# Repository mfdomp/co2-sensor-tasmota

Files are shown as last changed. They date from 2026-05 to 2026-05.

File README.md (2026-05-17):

# CO2 Sensor — ESP32 + Tasmota

Monitor de qualidade do ar com ESP32, sensor SCD41, display OLED, RTC e log em cartão SD. O firmware é o Tasmota 15.3.0.4 com script Berry (`autoexec.be`) que controla o display SSD1306 diretamente via I2C, sincroniza o DS3231 via NTP no boot e grava logs CSV no cartão SD.

## Funcionalidades

- Leitura de CO2 (ppm), temperatura (°C) e umidade relativa (%) via SCD41
- Display OLED SSD1306 128×64 com driver próprio em Berry (fonte 5×7, sem subsistema Display do Tasmota)
- Relógio em tempo real DS3231 — lido diretamente via I2C, sincronizado por NTP a cada boot
- Log CSV no cartão SD com timestamp local, gravado a cada 10 s; nome de arquivo gerado pela data/hora do boot
- Watchdog de software: reinicia o ESP32 se o loop principal travar por mais de 60 s
- Calibração forçada do SCD41 via função Berry `calibrar_scd41(ppm)` acessível pelo console
- Sem código C/C++ customizado — só Berry script + configuração Tasmota

## Implementações futuras

- Telemetria MQTT (publicação de leituras via broker MQTT usando o subsistema nativo do Tasmota)

## Hardware

| Componente | Descrição |
|---|---|
| ESP32-D0WD-V3 | Módulo principal (ex.: DevKit-C V4 38 pinos) |
| SCD41 | Sensor CO2 fotoacústico ± 40 ppm (I2C 0x62) |
| SSD1306 | Display OLED 0,96″ 128×64 px (I2C 0x3C) |
| DS3231 | Módulo RTC alta precisão (I2C 0x68) |
| Módulo MicroSD | Adaptador SPI para cartão MicroSD |

Todos os dispositivos I2C compartilham o mesmo barramento (GPIO 21/22).  
O cartão SD usa SPI dedicado (GPIO 5/18/19/23).

## Estrutura do repositório

```
co2-sensor-tasmota/
├── README.md
├── LICENSE
├── docs/
│   ├── bom.md          # Bill of Materials detalhada
│   ├── wiring.md       # Diagrama de conexões e pinagem
│   └── setup.md        # Guia completo de configuração
├── firmware/
│   ├── autoexec.be     # Script Berry principal (carregar no Tasmota)
│   └── tasmota/
│       ├── tasmota_template.json  # Template de GPIOs para Tasmota
│       └── backlog_config.txt     # Comandos de configuração via console
└── hardware/
    └── pinout.md       # Tabela de pinos ESP32 ↔ periféricos
```

## Acesso à Interface Web

### Android (recomendado para uso em campo)
1. Conecte ao WiFi `Sensor-XXXXXX`
2. Quando aparecer "Esta rede não tem internet, deseja continuar?" — confirme **Sim**
3. Abra o navegador e acesse `http://192.168.4.1`

### Windows
1. Conecte ao WiFi `Sensor-XXXXXX`
2. Ignore o aviso "Ação necessária"
3. Abra o navegador **manualmente** e acesse `http://192.168.4.1`
4. **Atenção:** O Windows pode desconectar automaticamente redes sem internet. Se isso ocorrer, reconecte e acesse rapidamente.
   - Para evitar: Configurações → Rede e Internet → WiFi → `Sensor-XXXXXX` → Propriedades → desabilitar troca automática de rede

### iOS
1. Conecte ao WiFi `Sensor-XXXXXX`
2. Ignore o aviso de portal cativo
3. Abra o Safari e acesse `http://192.168.4.1`

### Endereço fixo
O sensor sempre opera em `http://192.168.4.1` no modo AP.

## Início rápido

1. **Grave o firmware Tasmota** no ESP32 — veja [`docs/setup.md`](docs/setup.md).
2. **Conecte os componentes** conforme [`hardware/pinout.md`](hardware/pinout.md).
3. **Configure os GPIOs e drivers** via console Tasmota com os comandos em [`firmware/tasmota/backlog_config.txt`](firmware/tasmota/backlog_config.txt).
4. **Carregue o script Berry** copiando [`firmware/autoexec.be`](firmware/autoexec.be) via Tasmota File Manager (`Tools → Manage File System`).
5. **Reinicie** o dispositivo. O display acende ~21 s após o boot.

## Layout do display

```
28/04/2025        ← data (DS3231)
14:30             ← hora (DS3231)

CO2:512 ppm       ← leitura SCD41

T:22.5C H:45%     ← temperatura e umidade

192.168.1.42      ← IP Wi-Fi
```

Linha em branco entre grupos = página vazia no SSD1306 (fonte 5×7, 6 px por coluna).

## Log CSV

O arquivo é criado no cartão SD com nome baseado na data e hora do boot:

```
/sd/co2_20250428_1430.csv
```

Cabeçalho e formato:

```csv
datetime,co2,temperature,humidity
28/04/2025 14:30:00,512,22.5,45
28/04/2025 14:30:10,515,22.5,45
```

Gravação a cada **10 segundos**. Cada reinicialização cria um novo arquivo.

## Calibração do SCD41

Para calibração forçada pelo ar exterior (~420 ppm), execute no console Tasmota:

```
Br calibrar_scd41(420)
```

A função interrompe a medição, aguarda 3 s, aplica a calibração forçada (Forced Recalibration — FRC) e retoma automaticamente.

## Dependências de firmware

- [Tasmota 15.3.0.4](https://github.com/arendst/Tasmota) — build `tasmota32.bin`
- Nenhuma biblioteca externa — tudo incluso no Tasmota

## Licença

MIT — veja [`LICENSE`](LICENSE).

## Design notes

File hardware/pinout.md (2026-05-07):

# Pinagem — ESP32 DevKit-C V4 × Periféricos

## Barramento I2C (GPIO 21 / 22)

Todos os três dispositivos compartilham o **mesmo barramento I2C**. Os resistores de pull-up (4,7 kΩ para 3,3 V) devem estar presentes — muitos módulos breakout já os incluem.

| Sinal I2C | GPIO ESP32 | SCD41 | SSD1306 | DS3231 |
|---|---|---|---|---|
| SDA | **GPIO 21** | SDA | SDA | SDA |
| SCL | **GPIO 22** | SCL | SCL | SCL |
| VCC | 3,3 V | VDD | VCC | VCC |
| GND | GND | GND | GND | GND |

Endereços I2C padrão:

| Dispositivo | Endereço (hex) | Endereço (decimal) |
|---|---|---|
| SCD41 | 0x62 | 98 |
| SSD1306 | 0x3C | 60 |
| DS3231 | 0x68 | 104 |

> Para confirmar os endereços no Tasmota: `I2CScan` no console.

## SPI — Módulo MicroSD (GPIO 5/18/19/23)

| Sinal SPI | GPIO ESP32 | Módulo SD |
|---|---|---|
| MOSI | **GPIO 23** | MOSI / DI |
| MISO | **GPIO 19** | MISO / DO |
| CLK | **GPIO 18** | SCK / CLK |
| CS | **GPIO 5** | CS / SS |
| VCC | 3,3 V | VCC |
| GND | GND | GND |

> Use módulos SD com nível lógico 3,3 V ou que incluam divisor de tensão. O ESP32 **não tolera** 5 V nos pinos de I/O.

## Diagrama de conexão simplificado

```
ESP32 DevKit-C V4
┌─────────────────────────────────────────────┐
│                                             │
│  3V3 ──┬─── VCC (SCD41)                    │
│        ├─── VCC (SSD1306)                  │
│        ├─── VCC (DS3231)                   │
│        └─── VCC (SD Module)                │
│                                             │
│  GND ──┬─── GND (SCD41)                   │
│        ├─── GND (SSD1306)                  │
│        ├─── GND (DS3231)                   │
│        └─── GND (SD Module)                │
│                                             │
│  GPIO21 (SDA) ──┬─── SDA (SCD41)          │
│                 ├─── SDA (SSD1306)         │
│                 └─── SDA (DS3231)          │
│                                             │
│  GPIO22 (SCL) ──┬─── SCL (SCD41)          │
│                 ├─── SCL (SSD1306)         │
│                 └─── SCL (DS3231)          │
│                                             │
│  GPIO23 (MOSI) ─── DI  (SD Module)        │
│  GPIO19 (MISO) ─── DO  (SD Module)        │
│  GPIO18 (CLK)  ─── SCK (SD Module)        │
│  GPIO5  (CS)   ─── CS  (SD Module)        │
│                                             │
└─────────────────────────────────────────────┘
```

## Recomendações de montagem

- Mantenha os fios I2C com **menos de 20 cm** para evitar problemas de integridade de sinal.
- O SCD41 precisa de **circulação de ar** — não enclausure hermeticamente.
- Coloque o DS3231 **longe de fontes de calor** para manter a precisão do RTC.
- Um capacitor de 100 nF entre VCC e GND próximo a cada módulo reduz ruído na alimentação.

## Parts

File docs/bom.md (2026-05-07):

# Bill of Materials (BOM)

Revisão: 1.0 — 2025

## Componentes principais

| # | Componente | Fabricante | Part Number | Qtd | Notas |
|---|---|---|---|---|---|
| 1 | Módulo ESP32-DevKit-C V4 | Espressif / genérico | ESP32-D0WD-V3 | 1 | 38 pinos, USB-C preferível |
| 2 | Sensor CO2 SCD41 | Sensirion | SCD41 (breakout) | 1 | I2C 0x62; alimentação 3,3 V |
| 3 | Display OLED 0,96″ 128×64 | SSD1306 | genérico | 1 | I2C 0x3C; tensão 3,3 V ou 5 V |
| 4 | Módulo RTC DS3231 | Maxim / genérico | DS3231 (breakout) | 1 | I2C 0x68; inclui bateria CR2032 |
| 5 | Módulo MicroSD SPI | genérico | — | 1 | Nível lógico 3,3 V |

## Componentes passivos e auxiliares

| # | Componente | Valor | Qtd | Notas |
|---|---|---|---|---|
| 6 | Resistor pull-up I2C | 4,7 kΩ 1/4 W | 2 | SDA e SCL; omitir se os módulos já têm pull-up integrado |
| 7 | Capacitor de desacoplamento | 100 nF cerâmico | 4 | Um por módulo, próximo ao VCC |
| 8 | Capacitor bulk | 10 µF eletrolítico | 1 | Na alimentação 3,3 V |
| 9 | Bateria CR2032 | — | 1 | Para o DS3231 |

## Alimentação

| # | Item | Especificação | Qtd | Notas |
|---|---|---|---|---|
| 10 | Fonte USB 5 V | ≥ 1 A | 1 | O ESP32 consome ~240 mA em pico de TX Wi-Fi |
| 11 | Cabo USB (gravação/energia) | USB-A → USB-C ou Micro-USB | 1 | Conforme o conector do módulo |
| 12 | Regulador 3,3 V (opcional) | AMS1117-3.3 | 1 | Somente se a placa DevKit não tiver regulador interno |

## Fixação e enclosure

| # | Item | Qtd | Notas |
|---|---|---|---|
| 13 | Protoboard / PCB perfurada | 1 | Para prototipagem |
| 14 | Jumpers Macho-Macho 20 cm | 20 | Para prototipagem |
| 15 | Caixa plástica ≥ 80×60×30 mm | 1 | Furar para saídas de ar no SCD41 |
| 16 | Parafuso M3 × 6 mm | 4 | Fixação da placa na caixa |

## Consumo estimado

| Componente | Corrente típica (3,3 V) |
|---|---|
| ESP32 (Wi-Fi ativo) | 160–240 mA |
| SCD41 | 15 mA (medição) / 0,4 mA (espera) |
| SSD1306 | 10–20 mA |
| DS3231 | < 1 mA |
| Módulo SD (leitura/escrita) | 50–100 mA |
| **Total estimado** | **~250–380 mA @ 3,3 V** |

## Custo estimado (2025, mercado brasileiro)

| Componente | Preço aproximado (R$) |
|---|---|
| ESP32-DevKit-C V4 | R$ 30–50 |
| SCD41 (breakout) | R$ 200–280 |
| SSD1306 OLED 0,96″ | R$ 15–25 |
| DS3231 (módulo com bateria) | R$ 15–25 |
| Módulo MicroSD | R$ 8–15 |
| Componentes passivos | R$ 5–10 |
| MicroSD card 8–32 GB | R$ 15–30 |
| **Total estimado** | **R$ 288–435** |

> O SCD41 é o componente mais caro (~60–65% do custo total). Uma alternativa econômica é o MH-Z19C (~R$ 80), porém com menor precisão e sem medição de umidade.

## Onde comprar

- [Filipeflop](https://www.filipeflop.com)
- [Makerstore](https://www.makerstore.com.br)
- [AliExpress](https://www.aliexpress.com) — SCD41 breakout da Sensirion
- [Mouser Brasil](https://br.mouser.com) — SCD41 original Sensirion

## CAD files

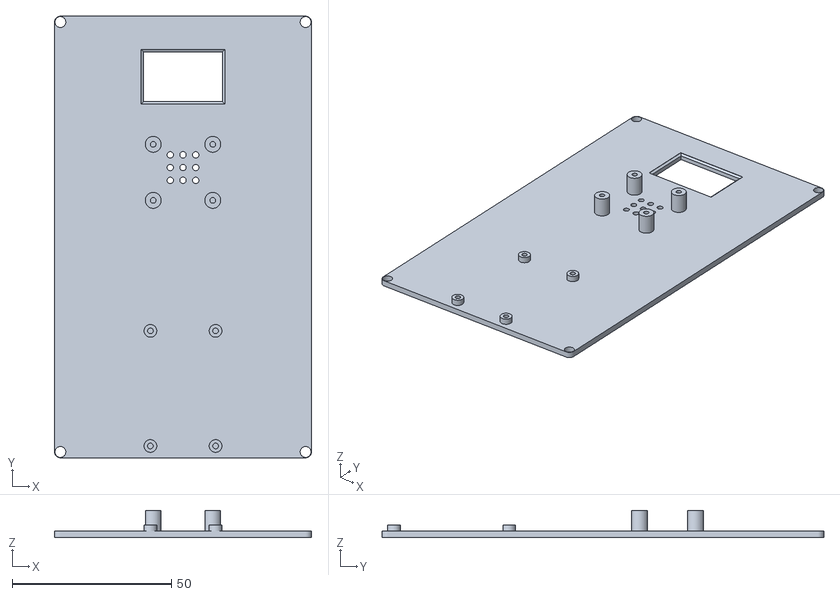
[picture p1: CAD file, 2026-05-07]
enclosure/stl/enclosure_lid.stl
80.7 x 138.7 x 8.50

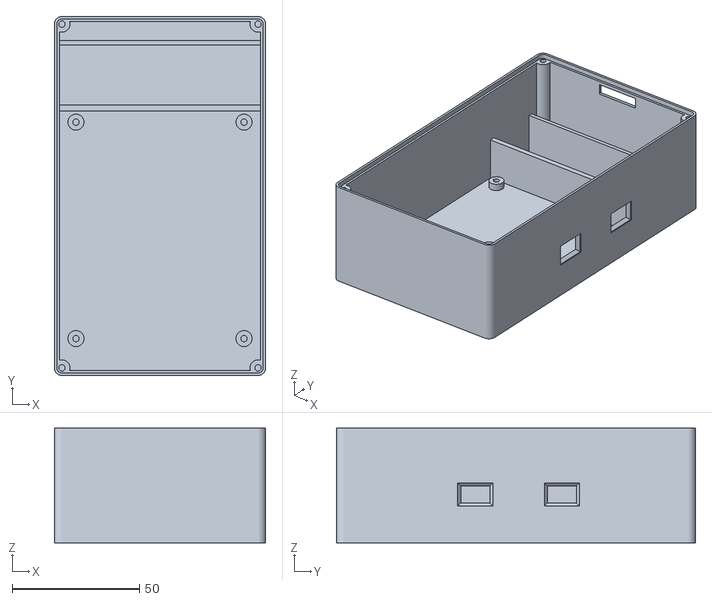
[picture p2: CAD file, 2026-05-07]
enclosure/stl/enclosure_base.stl
83.0 x 141.0 x 45.0

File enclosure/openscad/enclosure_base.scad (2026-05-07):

use <enclosure_v5_3_1.scad>
base();

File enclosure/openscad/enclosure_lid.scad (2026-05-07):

use <enclosure_v5_3_1.scad>
rotate([180, 0, 0]) translate([0, -125, -10]) lid();

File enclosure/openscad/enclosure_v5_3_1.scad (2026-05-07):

/* ============================================================
   ENCLOSURE v5
   83 × 141 × 47mm total  (base 45mm + tampa plana 2mm)
   Parede 2mm  |  Cantos R3mm

   MUDANÇAS v5 (em relação à v4):
   - BASE_H  30 → 45mm (+15mm)
   - Tampa   sem paredes laterais — placa plana 2mm
   - Encaixe rebaixo (rabbet) 1mm × 2mm no topo da base
     substitui o lábio/press-fit anterior
   - USB_Z   fixo no valor original (Z=11.6mm, base=30mm)
             NÃO recentralizado na nova altura
   - Slot MicroSD migra da tampa para a parede traseira da base
   - LIP_GAP=0.15mm (folga placa/rebaixo)

   COMPARTIMENTOS BASE:
     PCB  : Y  12..104 = 102mm de profundidade
     Rib  : Y 104..106 (furo Ø6mm fio da bateria)
     BAT  : Y 109..130 (bateria 18650: 75.6×21×18.2mm)
   ============================================================ */

$fn   = 64;
EPS   = 0.01;

// ── Caixa ────────────────────────────────────────────────────
ENC_W  = 83;
ENC_L  = 141;
WALL   = 2;
C_RAD  = 3;
BASE_H = 45;   // era 30mm — +15mm

// ── Tampa plana ───────────────────────────────────────────────
// Sem paredes laterais; standoffs pendurados para baixo.
// IT = distância do fundo da placa até referência dos componentes
// (inalterado → mantém posições OLED/SCD/MSD)
IT   = 13;

// ── Encaixe rebaixo (rabbet) ──────────────────────────────────
// Topo das paredes da base recebe um degrau de 1mm × 2mm.
// A placa tampa (80.7 × 138.7mm) assenta nesse degrau.
RABB_T  = 1.0;        // profundidade inward do rebaixo (1mm)
RABB_D  = WALL;       // altura do rebaixo = espessura da placa (2mm)
LIP_GAP = 0.15;       // folga lateral placa/degrau

LID_OFFSET = RABB_T + LIP_GAP;            // = 1.15mm
LID_W      = ENC_W - 2*LID_OFFSET;        // = 80.70mm
LID_L      = ENC_L - 2*LID_OFFSET;        // = 138.70mm
LID_R      = max(0.5, C_RAD - LID_OFFSET);// = 1.85mm

// ── Parafusos M3 ─────────────────────────────────────────────
BOSS_D   = 6;
BOSS_M   = 3;     // boss integrado ao canto (centro em 3,3)
PILOT_D  = 2.5;   // furo piloto auto-roscante no boss
SCREW_CL = 3.4;   // clearance M3

// ── PCB principal ─────────────────────────────────────────────
PCB_W   = 70;
PCB_L   = 90;
HOLE_DW = 66;
HOLE_DL = 85;
POST_OD = 6;
STAND_H = 3;
PCB_X0  = WALL + (ENC_W - 2*WALL - PCB_W) / 2;  // = 6.5mm
PCB_Y0  = WALL + 10;                              // = 12mm

// ── Parede divisória + furo fio bateria ──────────────────────
WIRE_RIB_Y = PCB_Y0 + PCB_L + 2;  // = 104mm
WIRE_RIB_T = 2.0;
WIRE_D     = 6.0;
WIRE_X     = ENC_W / 2;
WIRE_Z     = WALL + 18.2 / 2;     // centro vertical da bateria

// ── Bateria 18650 ─────────────────────────────────────────────
BAT_L    = 75.6;
BAT_W    = 21.0;
BAT_H    = 18.2;
BAT_RAIL = 1.5;
BAT_X0   = WALL + (ENC_W - 2*WALL - BAT_L) / 2;
BAT_Y0   = WIRE_RIB_Y + WIRE_RIB_T + 3;  // = 109mm

// ── Mini USB (Z FIXO — posição original com BASE_H=30mm) ─────
USB_W      = 7.39;
USB_H      = 2.73;
USB_MARGIN = 2.0;
USB_HW     = USB_W + 2*USB_MARGIN;
USB_HH     = USB_H + 2*USB_MARGIN;
USB_CH     = 1.2;
USB1_Y     = PCB_Y0 + (38.2 + (PCB_L - 43.2)) / 2; // = 54.5mm
USB2_Y     = PCB_Y0 + (74.0 + (PCB_L - 11.0)) / 2; // = 88.5mm
USB_Z      = (30 - USB_HH) / 2 + 4 +3.5 + 1.5;  // +4mm solicitado → ~15.6mm

// ── OLED (posições do v3_1) ───────────────────────────────────
OLED_PCB_W   = 27.2;
OLED_PCB_L   = 28.3;
OLED_HOLE_DW = 23.89;
OLED_HOLE_DL = 25;
OLED_WIN_W   = 24.7;
OLED_WIN_L   = 15.55;
OLED_STAND   = 1.5;
OLED_POST_D  = 5.0;
OLED_SCREW   = 1.8;
OLED_CX      = ENC_W / 2;
OLED_CY      = WALL + 4 + OLED_PCB_L / 2;

// ── SCD41 (posições do v3_1) ──────────────────────────────────
SCD_PCB_W    = 23.0;
SCD_PCB_L    = 21.8;
SCD_HOLE_DW  = 18.7;
SCD_HOLE_DL  = 17.6;
SCD_SENS_W   = 8.0;
SCD_SENS_L   = 8.0;
SCD_SENS_OFF = 5.4;
SCD_STAND    = 6.5;
SCD_POST_D   = 5.0;
SCD_SCREW    = 1.8;
SCD_CX       = ENC_W / 2;
SCD_Y0       = WALL + 4 + OLED_PCB_L + 5;
SCD_CY       = SCD_Y0 + SCD_PCB_L / 2;
SCD_SENS_CX  = SCD_CX;
SCD_SENS_CY  = SCD_Y0 + SCD_SENS_OFF + SCD_SENS_L / 2;

// ── MicroSD ───────────────────────────────────────────────────
MSD_PCB_W    = 24.2;
MSD_PCB_L    = 41.9;
MSD_HOLE_DW  = 20.45;
MSD_HOLE_DL  = 36.15;
MSD_PCB_H    = 1.59;
MSD_TOT_H    = 3.56;
MSD_CARD_W   = 18.0;
MSD_CARD_H   = 3.6;
MSD_STAND    = 2.0;
MSD_POST_D   = 4.0;
MSD_SCREW    = 1.8;
MSD_CX       = ENC_W / 2;
MSD_Y1       = ENC_L - WALL;
MSD_Y0       = MSD_Y1 - MSD_PCB_L;
MSD_CY       = MSD_Y0 + MSD_PCB_L / 2;

// Posição Z do slot do cartão — referenciada à BASE (Z absoluto)
// Placa tampa fundo: Z = BASE_H - WALL = 43mm
// PCB MSD topo:      Z = 43 - MSD_STAND = 41mm
// PCB MSD fundo:     Z = 41 - MSD_PCB_H = 39.41mm
// Cartão fundo:      Z = 39.41 - (MSD_TOT_H - MSD_PCB_H) = 37.44mm
MSD_PCB_TOP_BASE  = BASE_H - WALL - MSD_STAND;
MSD_PCB_BOT_BASE  = MSD_PCB_TOP_BASE - MSD_PCB_H;
MSD_CARD_BOT_BASE = MSD_PCB_BOT_BASE - (MSD_TOT_H - MSD_PCB_H);
MSD_CARD_CZ_BASE  = (MSD_PCB_BOT_BASE + MSD_CARD_BOT_BASE) / 2;
MSD_SLOT_M        = 0.5;   // margem extra no slot do cartão

// ════════════════════════════════════════════════════════════
// UTILITÁRIO
// ════════════════════════════════════════════════════════════
module rbox(w, l, h, r) {
    R = (r == undef) ? C_RAD : r;
    linear_extrude(h)
        hull()
            for (xi = [R, w-R], yi = [R, l-R])
                translate([xi, yi]) circle(r = R);
}

// ════════════════════════════════════════════════════════════
// BASE (45mm)
//
// Topo das paredes tem rebaixo de 1mm×2mm para receber a tampa.
// Boss de canto vai até BASE_H; exempt do rebaixo para manter
// acesso ao parafuso M3.
// USB fixo em Z=11.6mm (posição original).
// Slot MicroSD na parede traseira (Y=ENC_L).
// ════════════════════════════════════════════════════════════
module base() {

    pcb_cx = PCB_X0 + PCB_W/2;
    pcb_cy = PCB_Y0 + PCB_L/2;
    EE = 0.5;   // embute sólidos EE mm no fundo
    EX = 0.15;  // margem de exemption

    difference() {

        // ═══════════════════════════════════════
        // SÓLIDOS
        // ═══════════════════════════════════════
        union() {
            // Casco externo (45mm)
            rbox(ENC_W, ENC_L, BASE_H);

            // Boss de canto — topo alinhado com o piso do rebaixo (BASE_H-RABB_D=43mm)
            for (xi=[BOSS_M, ENC_W-BOSS_M],
                 yi=[BOSS_M, ENC_L-BOSS_M])
                translate([xi, yi, WALL-EE])
                    cylinder(d=BOSS_D, h=BASE_H-RABB_D-WALL+EE);

            // Standoffs PCB (M3)
            for (dx=[-HOLE_DW/2, HOLE_DW/2],
                 dy=[-HOLE_DL/2, HOLE_DL/2])
                translate([pcb_cx+dx, pcb_cy+dy, WALL-EE])
                    cylinder(d=POST_OD, h=STAND_H+EE);

            // Rail traseiro bateria
            translate([WALL, BAT_Y0+BAT_W, WALL-EE])
                cube([ENC_W-2*WALL, BAT_RAIL, BAT_H+EE]);

            // Parede divisória PCB/bateria
            translate([WALL-EE, WIRE_RIB_Y, WALL-EE])
                cube([ENC_W-2*WALL+2*EE, WIRE_RIB_T, BAT_H+EE]);
        }

        // ═══════════════════════════════════════
        // CORTES
        // ═══════════════════════════════════════
        union() {

            // ── Cavidade principal (c/ exemptions) ───────
            difference() {
                translate([WALL, WALL, WALL])
                    rbox(ENC_W-2*WALL, ENC_L-2*WALL,
                         BASE_H-WALL, C_RAD-WALL);

                // Exempt bosses
                for (xi=[BOSS_M, ENC_W-BOSS_M],
                     yi=[BOSS_M, ENC_L-BOSS_M])
                    translate([xi, yi, WALL-EE-EPS])
                        cylinder(d=BOSS_D+2*EX,
                                 h=BASE_H-RABB_D-WALL+EE+2*EPS);

                // Exempt standoffs PCB
                for (dx=[-HOLE_DW/2, HOLE_DW/2],
                     dy=[-HOLE_DL/2, HOLE_DL/2])
                    translate([pcb_cx+dx, pcb_cy+dy, WALL-EE-EPS])
                        cylinder(d=POST_OD+2*EX,
                                 h=STAND_H+EE+2*EPS);

                // Exempt rail bateria
                translate([WALL-EX, BAT_Y0+BAT_W-EX, WALL-EE-EPS])
                    cube([ENC_W-2*WALL+2*EX,
                          BAT_RAIL+EX, BAT_H+EE+2*EPS]);

                // Exempt rib divisória
                translate([WALL-EE-EX, WIRE_RIB_Y-EX, WALL-EE-EPS])
                    cube([ENC_W-2*WALL+2*EE+2*EX,
                          WIRE_RIB_T+2*EX, BAT_H+EE+2*EPS]);
            }

            // ── Rebaixo (rabbet) para encaixe da tampa ────
            // 1mm inward × 2mm deep — bosses já terminam em Z=43mm
            // (BASE_H-RABB_D), não precisam de exemption aqui
            translate([RABB_T, RABB_T, BASE_H-RABB_D-EPS])
                rbox(ENC_W-2*RABB_T, ENC_L-2*RABB_T,
                     RABB_D+2*EPS, C_RAD-RABB_T);
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

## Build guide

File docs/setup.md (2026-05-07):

# Guia de Configuração

## Pré-requisitos

- Python 3.8+ (para esptool, se for gravar via serial)
- Cartão MicroSD FAT32, até 32 GB
- Módulo ESP32 conectado via USB (para flash inicial)

## 1. Instalar o firmware Tasmota no ESP32

Este projeto fornece um firmware pré-compilado em `firmware/tasmota32-custom.zip` com todos os drivers necessários (SCD41, DS3231, SD Card, Berry). Extraia o `.bin` antes de gravar.

> Se já tiver um Tasmota qualquer rodando no ESP32, use a **Opção D (OTA)** — mais prática.

### Opção A — esptool manual (recomendado para flash inicial)

```bash
pip install esptool

# Apaga a flash
esptool.py --chip esp32 --port /dev/ttyUSB0 erase_flash

# Grava o firmware (offset 0x0 para binários Tasmota ESP32)
esptool.py --chip esp32 --port /dev/ttyUSB0 \
  --baud 921600 write_flash -z 0x0 tasmota32-custom.bin
```

No Windows, substitua `/dev/ttyUSB0` por `COM3` (ou a porta correta).

### Opção B — tasmota-install

```bash
pip install tasmota-install
tasmota-install
```

Selecione a porta serial e aponte para o `tasmota32-custom.bin` extraído do zip.

### Opção C — Tasmota Web Installer

Acesse [https://tasmota.github.io/install/](https://tasmota.github.io/install/) via Chrome/Edge, conecte o ESP32 via USB e selecione o arquivo `tasmota32-custom.bin`.

### Opção D — Atualização OTA (para dispositivos já com Tasmota)

1. Na interface web do dispositivo, vá em **Firmware Upgrade → Upgrade by file upload**.
2. Selecione o arquivo `tasmota32-custom.bin` extraído do zip.
3. Clique em **Start upgrade**.
4. O dispositivo reinicia automaticamente com o novo firmware.

> Não é necessário apagar a flash no upgrade OTA — as configurações de Wi-Fi e GPIOs são preservadas.

## 2. Configuração inicial do Wi-Fi

1. Após gravar, o ESP32 cria uma rede Wi-Fi chamada **tasmota-XXXXXX**.
2. Conecte-se a ela e acesse `http://192.168.4.1`.
3. Configure o SSID e a senha da sua rede.
4. O dispositivo reinicia e obtém um IP na sua rede.

## 3. Aplicar o template de GPIOs

1. Acesse a interface web do dispositivo: `http://<ip-do-dispositivo>`.
2. Vá em **Configuration → Configure Other**.
3. Cole o conteúdo de `firmware/tasmota/tasmota_template.json` no campo **Template**.
4. Marque **Activate** e clique em **Save**.
5. O dispositivo reinicia com os GPIOs mapeados.

### Mapeamento do template

| GPIO | Código Tasmota | Periférico |
|---|---|---|
| GPIO 5  | 6720 — SD Card CS | SD Card |
| GPIO 18 | 736 — SPI CLK | SD Card |
| GPIO 19 | 672 — SPI MISO | SD Card |
| GPIO 21 | 640 — I2C SDA | SCD41, SSD1306, DS3231 |
| GPIO 22 | 608 — I2C SCL | SCD41, SSD1306, DS3231 |
| GPIO 23 | 704 — SPI MOSI | SD Card |

> O script Berry também aplica esses GPIOs via `setup_gpio()` no boot, mas o template garante o mapeamento correto desde o primeiro reinício.

## 4. Configurar drivers via console

Acesse **Tools → Console** na interface web e execute:

```
# Drivers I2C: SCD41 (44) e DS3231 (56)
Backlog I2CDriver44 1; I2CDriver56 1

# Fuso horário UTC-3 (Brasília) para NTP
Backlog Timezone -3; TimeDST 0,0,0,0,0,-2; TimeSTD 0,0,0,0,0,-3

# Reiniciar
Restart 1
```

> O display SSD1306 é controlado diretamente pelo script Berry via `wire1` — **não** configure `DisplayModel` nem `DisplayMode`. O subsistema de Display do Tasmota não é utilizado.

## 5. Verificar detecção dos sensores

Após reiniciar, no console:

```
I2CScan
```

Saída esperada:
```
I2C Device found at address 0x3C  (SSD1306)
I2C Device found at address 0x62  (SCD41)
I2C Device found at address 0x68  (DS3231)
```

```
Status 8
```

Deve retornar JSON com campos `SCD41.CarbonDioxide`, `SCD41.Temperature`, `SCD41.Humidity`.

## 6. Preparar o cartão SD

1. Formate o cartão como **FAT32**.
2. Insira no módulo SD (conectado ao ESP32).
3. No console Tasmota, verifique:

```
SDInfo
```

Saída esperada:
```
{"SDCard":{"Mounted":1,"Free":14982144,"Used":0,"Total":14982144}}
```

## 7. Carregar o script Berry

1. Na interface web, vá em **Tools → Manage File System**.
2. Clique em **Choose File** e selecione `firmware/autoexec.be`.
3. Clique em **Upload**.
4. Reinicie o dispositivo:

```
Restart 1
```

O script aguarda **20 s** após o boot antes de inicializar (tempo de estabilização do Tasmota e do Wi-Fi). O display acende ~1 s depois, exibindo as primeiras leituras em ~21 s no total.

## 8. Sincronização do DS3231

O script sincroniza o DS3231 automaticamente via NTP (usando `tasmota.rtc()`) no boot, desde que haja conexão com a internet. O RTC mantém o horário mesmo sem energia no ESP32 (bateria CR2032).

Para definir a hora manualmente (sem internet):

```
Time 2025-04-28T14:30:00
Restart 1
```

O script usa o horário do Tasmota (UTC-3) para sincronizar o DS3231 na próxima reinicialização.

## 9. Calibração do SCD41

Para calibração forçada com ar externo (~420 ppm CO₂):

```
Br calibrar_scd41(420)
```

A função para a medição, aguarda 3 s, aplica FRC (Forced Recalibration) e imprime confirmação no console. Execute em ambiente externo ventilado com o sensor estabilizado por pelo menos 3 minutos.

## Solução de problemas

| Sintoma | Causa provável | Solução |
|---|---|---|
| Display não liga após 21 s | GPIO errado ou endereço I2C | Verificar pinagem e `I2CScan` |
| SCD41 não detectado | Endereço I2C errado ou pull-ups faltando | Verificar 4,7 kΩ no SDA/SCL |
| SD não montado | Formato incorreto ou CS errado | Formatar FAT32; confirmar GPIO5=6720 no template |
| `Status 8` sem SCD41 | Driver I2CDriver44 não habilitado | `I2CDriver44 1` + `Restart 1` |
| Hora incorreta no display | DS3231 sem bateria ou NTP indisponível | Verificar CR2032; usar `Time` manual + `Restart 1` |
| Log não criado | SD não montado no momento do boot | Reiniciar após confirmar `SDInfo` |
| ESP32 reinicia sozinho | Watchdog ativo (loop travado) | Verificar console para mensagem `ALERTA: loop travado!` |

## Recompilação customizada (opcional)

O firmware em `firmware/tasmota32-custom.zip` já foi compilado com as flags abaixo. Recompile apenas se precisar alterar drivers ou versão do Tasmota.

```c
// user_config_override.h
#define USE_SCD40         // SCD41 sensor (driver cobre ambos os modelos)
#define USE_DS3231        // RTC DS3231
#define USE_BERRY         // scripting Berry
#define USE_SDCARD        // suporte SD card
```

> `USE_DISPLAY` e `USE_DISPLAY_SSD1306` **não são necessários** — o script controla o SSD1306 diretamente via I2C.

Use PlatformIO com o `platformio.ini` do repositório Tasmota.

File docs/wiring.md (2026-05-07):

# Diagrama de Fiação

## Visão geral

```
                    ┌──────────────┐
                    │   ESP32      │
                    │  DevKit-C V4 │
         ┌──────────┤ GPIO21 (SDA) │
         │          │ GPIO22 (SCL) │────────────┐
         │          │              │            │
         │    ┌─────┤ GPIO23 MOSI  │            │
         │    │ ┌───┤ GPIO19 MISO  │            │
         │    │ │ ┌─┤ GPIO18 CLK   │            │
         │    │ │ │ ┤ GPIO5  CS    │            │
         │    │ │ │ │              │            │
         │    │ │ │ │ 3V3 ─────────┼─── VCC     │
         │    │ │ │ │ GND ─────────┼─── GND     │
         │    │ │ │ └──────────────┘            │
         │    │ │ │                             │
         │    │ │ │    MicroSD Module           │
         │    │ │ │  ┌──────────────┐           │
         │    └─┼─┼──┤ MOSI         │           │
         │      └─┼──┤ MISO         │           │
         │        └──┤ SCK          │           │
         │           ┤ CS           │           │
         │           │ VCC ── 3V3   │           │
         │           │ GND ── GND   │           │
         │           └──────────────┘           │
         │                                      │
         │  I2C Bus (SDA/SCL)                   │
         │  ┌──────────────┐                    │
         └──┤ SDA  SCD41   │                    │
            ┤ SCL          │────────────────────┤
            │ VDD ── 3V3   │                    │
            │ GND ── GND   │                    │
            └──────────────┘                    │
                                                │
            ┌──────────────┐                    │
            ┤ SDA SSD1306  │────────────────────┤
            ┤ SCL (OLED)   │────────────────────┤
            │ VCC ── 3V3   │                    │
            │ GND ── GND   │                    │
            └──────────────┘                    │
                                                │
            ┌──────────────┐                    │
            ┤ SDA  DS3231  │────────────────────┘
            ┤ SCL  (RTC)   │────────────────────
            │ VCC ── 3V3   │
            │ GND ── GND   │
            └──────────────┘
```

## Pull-ups I2C

Se os módulos não incluírem resistores de pull-up internos, adicione 4,7 kΩ entre:
- SDA (GPIO21) → 3,3 V
- SCL (GPIO22) → 3,3 V

A maioria dos breakouts para SSD1306 e DS3231 já inclui pull-ups. O breakout do SCD41 geralmente **não** inclui — adicione nesse caso.

## Alimentação

```
Fonte USB 5V
     │
     └── ESP32 (USB / VIN)
              │
              └── Regulador interno 3,3 V
                         │
                         ├── SCD41
                         ├── SSD1306
                         ├── DS3231
                         └── Módulo SD
```

**Corrente máxima do regulador onboard do DevKit-C:** ~600 mA (AMS1117-3.3). Com todos os periféricos ativos + Wi-Fi, fique abaixo de 500 mA para margem de segurança.

## Verificação de fiação

Após montar, use o console Tasmota para verificar:

```
I2CScan
```

Saída esperada:
```
I2C Driver List: 
I2C Device found at address 0x3C   (SSD1306)
I2C Device found at address 0x62   (SCD41)
I2C Device found at address 0x68   (DS3231)
```

Se algum dispositivo não aparecer, verifique:
1. Conexões SDA/SCL no módulo correto
2. Alimentação 3,3 V no módulo
3. Pull-ups presentes no barramento

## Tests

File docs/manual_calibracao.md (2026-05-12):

# Sensor CO₂ — Manual de Calibração Rápida

**SCD41 · Tasmota 15.3.0.4 · Berry Script**  
[github.com/mfdomp/co2-sensor-tasmota](https://github.com/mfdomp/co2-sensor-tasmota)

---

> ⚠️ **Atenção:** A calibração forçada substitui a referência interna do sensor.  
> Realize somente em ambiente com concentração de CO₂ **conhecida e estável**.  
> Aguarde **3 minutos** de estabilização antes de executar.

---

## Passo 1 — Conectar ao Sensor

Ligue o sensor e conecte ao WiFi **Sensor-XXXXXX** (os 6 últimos dígitos são o MAC Address do dispositivo).

Abra o navegador e acesse:

```
http://192.168.4.1
```

A página inicial exibe as leituras em tempo real do SCD41 (CO₂ em ppm, temperatura e umidade).

> 💡 Confirme que o sensor está operando e exibindo valores antes de iniciar a calibração.

---

## Passo 2 — Abrir o Berry Scripting Console

Na página inicial, clique em **Tools** e em seguida em **Berry Scripting Console**.

---

## Passo 3 — Estabilizar o Sensor

Coloque o sensor no ambiente de referência e aguarde **no mínimo 3 minutos** para estabilização térmica e química completa.

| Referência | Concentração típica |
|---|---|
| Ar externo (outdoor) | ~420 ppm |
| Ambiente controlado | Valor do equipamento de referência |
| Câmara de calibração | Valor injetado na câmara |

---

## Passo 4 — Executar a Calibração

No Berry Scripting Console, digite o comando abaixo substituindo o valor pelo ppm real do seu ambiente, e pressione **Run code**:

```berry
calibrar_scd41(420)
```

> ✅ Após alguns segundos aparecerá a mensagem de confirmação:  
> **`Calibracao enviada: 420 ppm`**

> 💡 A calibração é gravada na EEPROM interna do SCD41 e persiste mesmo após desligar o sensor.

---

## Passo 5 — Verificar o Resultado

Volte à página inicial (`http://192.168.4.1`) e verifique se o valor de **Carbon Dioxide** está próximo ao valor de referência utilizado.

Aguarde 1–2 ciclos de medição (cada ciclo dura ~5 segundos) para confirmar a estabilização.

> ⚠️ **Se o valor ainda estiver muito diferente do esperado:** Aguarde mais 3 minutos e repita o procedimento a partir do Passo 3.

---

## Referência de Comandos

### Calibração

| Comando | Descrição |
|---|---|
| `calibrar_scd41(420)` | Calibrar usando ar externo como referência (~420 ppm) |
| `calibrar_scd41(N)` | Calibrar usando `N` ppm como valor de referência |

### Log e Intervalo de Amostragem

| Comando | Descrição |
|---|---|
| `LOG_INTERVAL=60` | Alterar intervalo de gravação no SD para 60 segundos |
| `LOG_INTERVAL=10` | Restaurar intervalo de gravação para 10 segundos (padrão) |

---

*Sensor CO₂ — Tasmota 15.3.0.4 | SCD41 + ESP32-D0WD-V3*

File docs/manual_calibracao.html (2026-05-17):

# 🌿 Sensor CO₂

## Manual de Calibração Rápida

SCD41 Tasmota 15.3.0.4 Berry Script

github.com/mfdomp/co2-sensor-tasmota

⚠️ Atenção: A calibração forçada substitui a referência interna do sensor. Realize somente em ambiente com concentração de CO₂ conhecida e estável. Aguarde 3 minutos de estabilização antes de executar.

📶

### Acesso à Interface Web

O sensor cria uma rede WiFi própria. Conecte ao WiFi Sensor-XXXXXX e acesse http://192.168.4.1 no navegador.

Sistema | Como acessar
Android ✅ recomendado | Conecte ao WiFi → confirme "continuar sem internet" → abra o navegador e acesse o endereço
Windows | Conecte ao WiFi → ignore "Ação necessária" → abra o navegador manualmente e acesse o endereço. Se desconectar, reconecte e acesse rapidamente.
iOS | Conecte ao WiFi → ignore aviso de portal cativo → abra o Safari e acesse o endereço

O sensor sempre opera em http://192.168.4.1 no modo AP.

1

### Conectar ao Sensor

Ligue o sensor e conecte ao WiFi Sensor-XXXXXX (onde XXXXXX são os 6 últimos dígitos do MAC Address).

Abra o navegador e acesse: http://192.168.4.1

A página inicial exibe as leituras em tempo real do SCD41:

Página Inicial

Página inicial com leituras do sensor

💡 Confirme que o sensor está lendo valores próximos ao esperado antes de calibrar.

2

### Acessar o Menu Tools

Na página inicial clique em Tools para acessar as ferramentas avançadas.

Menu Tools

Menu Tools com opções avançadas

Em seguida clique em Berry Scripting Console.

3

### Estabilizar o Sensor

Coloque o sensor no ambiente com CO₂ conhecido e aguarde no mínimo 3 minutos para estabilização completa.

Referência | Concentração típica
Ar externo (outdoor) | ~420 ppm
Ambiente controlado | Valor do equipamento de referência
Câmara de calibração | Valor injetado na câmara

4

### Executar a Calibração

No Berry Scripting Console, digite o comando com o valor de referência em ppm e pressione Run code:

Berry Console

Berry Scripting Console

calibrar_scd41(900)

Substitua 900 pelo valor real do seu ambiente de referência.

✅ Após alguns segundos aparecerá a mensagem:
Calibracao enviada: 900 ppm

💡 A calibração é salva na EEPROM interna do SCD41 e persiste após desligar o sensor.

5

### Verificar o Resultado

Volte à página inicial (http://192.168.4.1) e verifique se o valor de Carbon Dioxide está próximo ao valor de referência utilizado.

Aguarde 1-2 ciclos de medição (cada ciclo dura 5 segundos) para confirmar a estabilização.

⚠️ Se o valor estiver muito diferente: Aguarde mais 3 minutos de estabilização e repita o procedimento.

ℹ️

### Referência de Comandos

Comando | Descrição
calibrar_scd41(420) | Calibrar com ar externo (~420 ppm)
calibrar_scd41(900) | Calibrar com 900 ppm de referência
LOG_INTERVAL=60 | Alterar intervalo de log para 60 segundos
LOG_INTERVAL=10 | Voltar intervalo de log para 10 segundos

Sensor CO₂ — Tasmota 15.3.0.4 | SCD41 + ESP32-D0WD-V3
github.com/mfdomp/co2-sensor-tasmota

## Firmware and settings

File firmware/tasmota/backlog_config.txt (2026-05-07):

# Tasmota 15.3.0.4 — Comandos de configuração via console
# Cole cada bloco no console web: http://<ip-do-dispositivo>/cs
# Use "Backlog" para executar múltiplos comandos em sequência.
#
# AVISO: substitua os valores entre <> pelas suas configurações reais.

# ─── 1. Identidade do dispositivo ───────────────────────────────────────────
Backlog Hostname co2-sensor; FriendlyName CO2 Sensor; Topic co2sensor

# ─── 2. Wi-Fi (se não configurado pelo processo de setup inicial) ────────────
# Backlog SSID1 <sua-rede-wifi>; Password1 <sua-senha-wifi>

# ─── 3. MQTT (opcional — remover se não usar broker MQTT) ───────────────────
# Backlog MqttHost <ip-do-broker>; MqttPort 1883; MqttUser <usuario>; MqttPassword <senha>

# ─── 4. Template de GPIOs ───────────────────────────────────────────────────
# Cole o conteúdo de tasmota_template.json no campo "Configuration → Configure Other → Template",
# marque "Activate" e salve. Ou execute via console:
Template {"NAME":"CO2-Sensor-ESP32","GPIO":[1,1,1,1,1,6720,1,1,1,1,1,1,1,1,1,1,1,1,736,672,1,640,608,704,1,1,1,1,1,1,1,1,1,1,1,1,1,1],"FLAG":0,"BASE":1}
Module 0

# Mapeamento:
#   GPIO 5  = 6720 → SD Card CS
#   GPIO 18 = 736  → SPI CLK
#   GPIO 19 = 672  → SPI MISO
#   GPIO 21 = 640  → I2C SDA  (SCD41, SSD1306, DS3231)
#   GPIO 22 = 608  → I2C SCL  (SCD41, SSD1306, DS3231)
#   GPIO 23 = 704  → SPI MOSI

# ─── 5. Drivers I2C ─────────────────────────────────────────────────────────
# Habilita SCD41 (driver 44) e DS3231 RTC (driver 56)
# NÃO configure DisplayModel — o SSD1306 é controlado diretamente pelo script Berry
Backlog I2CDriver44 1; I2CDriver56 1

# ─── 6. Telemetria MQTT (implementação futura) ──────────────────────────────
# Backlog TelePeriod 60; SetOption8 0; SetOption19 0

# ─── 7. Fuso horário (UTC-3 = Brasília) ─────────────────────────────────────
# Necessário para que sync_rtc() grave a hora correta no DS3231
Backlog Timezone -3; TimeDST 0,0,0,0,0,-2; TimeSTD 0,0,0,0,0,-3

# ─── 8. Verificação ─────────────────────────────────────────────────────────
# Execute após reiniciar para confirmar que os sensores foram detectados:
#   I2CScan          → lista dispositivos I2C (0x3C, 0x62, 0x68 esperados)
#   Status 8         → mostra dados dos sensores (chave SCD41)
#   SDInfo           → mostra informações do cartão SD

# ─── Sequência de configuração recomendada ──────────────────────────────────
# 1. Template + Module 0            → aplica mapeamento de GPIOs → reinicia
# 2. I2CDriver44 + I2CDriver56      → habilita drivers SCD41 e DS3231
# 3. TelePeriod + Timezone          → ajusta telemetria e fuso horário
# 4. Reiniciar: Restart 1
# 5. Conferir com I2CScan e Status 8
# 6. Inserir cartão SD formatado FAT32; conferir com SDInfo
# 7. Fazer upload de firmware/autoexec.be via Tools → Manage File System
# 8. Reiniciar: Restart 1
# 9. Display acende ~21 s após o boot

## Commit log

2026-05-07 Add autoexec.be and sync all docs to new firmware
    - Add firmware/autoexec.be: raw SSD1306 driver via wire1 (5x7 font),
    DS3231 direct I2C read/write, sync_rtc() via NTP, log every 10 s with
    date/time filename, software watchdog, calibrar_scd41() helper
    - Fix tasmota_template.json: GPIO5=6720 (SD CS), add GPIO18=736 (SPI CLK)
    and GPIO19=672 (SPI MISO) that were missing
    - Update backlog_config.txt: remove Display commands (SSD1306 driven raw),
    correct GPIO mapping comments, update setup sequence
    - Update README and docs/setup.md to reflect Tasmota 15.3.0.4, new display
    architecture, 10 s log interval, calibration and watchdog features
    - Sync firmware/berry/autoexec.be with new canonic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
    [backlog_config.txt]
2026-05-07 Move MQTT telemetry to future implementations
    [backlog_config.txt]
2026-05-07 Add enclosure files
    [enclosure_base.scad, enclosure_base.stl, enclosure_lid.scad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]
2026-05-12 Fix setup_gpio I2C check and add safety to setup_identity
    - setup_gpio: verifica valor inteiro 640 (código Tasmota para I2C SDA1)
    em vez de string, evitando erro de runtime; envolve em try/except
    - setup_identity: usa wifi().find('mac', '') com checagem de tamanho
    para não quebrar quando o MAC ainda não está disponível
2026-05-12 Add check_sdcard() to detect missing SD card at boot
    Tenta abrir /sd/.check antes de inicializar o log. Se o SDCard não
    estiver presente, exibe "Insira o SDCard!" na página 3 do display e
    aborta init_logfile(). Display é inicializado antes do check para
    permitir a exibição da mensagem.
2026-05-12 Remove /sd/.check after SD card probe
    Deletes the test file imediatamente após fechar, evitando acúmulo de
    arquivos vazios no cartão a cada boot.
2026-05-12 Fix WiFi instability and persistent SD card warning on display
    - setup_identity: reinicia apos alterar hostname para evitar estado
    inconsistente no WiFi; em boots subsequentes o nome ja esta correto
    e o restart nao ocorre
    - check_sdcard: usa flag global SD_OK em vez de escrever direto no
    display (a mensagem era sobrescrita pelo disp_loop em 1 segundo)
    - update_display: exibe 'SD ausente!' na pagina 2 de forma persistente
    quando SD_OK == false
2026-05-12 Add calibration quick guide with screenshots
2026-05-14 Fix calibrar_scd41(): correct I2C commands and transaction structure
    - Stop command: 0x3603 (invalid) → 0x3F86 (stop_periodic_measurement)
    - FRC command: 0x3627 (wrong) → 0x362F (perform_forced_recalibration)
    - Merge three separate I2C writes into one transaction (size=4, big-endian)
    - Add 400ms delay after FRC as required by SCD41 datasheet
    - Add restart of periodic measurement (0x21B1) after calibration
2026-05-14 Use target variable in calibrar_scd41 print statement
